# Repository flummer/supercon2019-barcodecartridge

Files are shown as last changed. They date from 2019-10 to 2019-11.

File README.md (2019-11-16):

# Barcode reader Cartridge for the 2019 Hackaday Superconference Badge

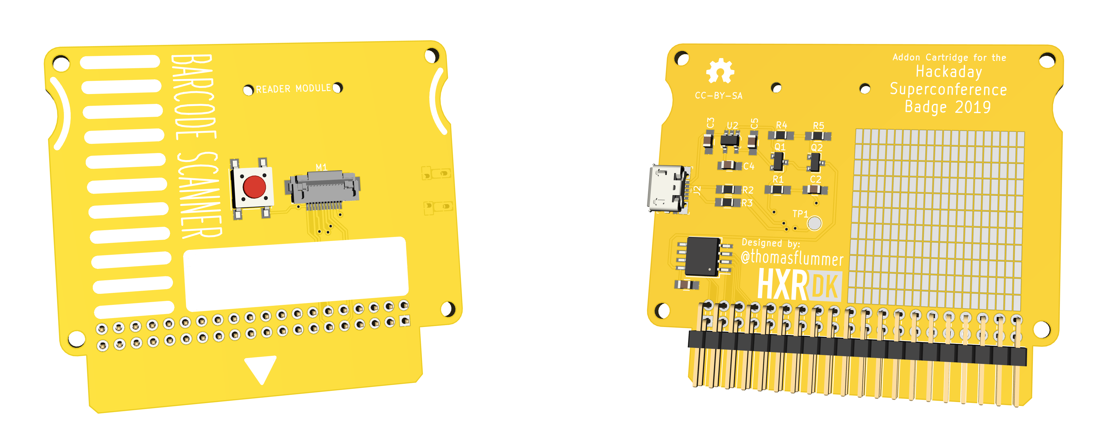
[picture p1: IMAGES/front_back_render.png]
Barcode Cartridge render


This is designed to use the GM65 barcode reader module, that supports both 1D and 2D barcodes and is able to read from a screen (eg. a smartphone or the screen on the badge)

This cartridge is based on the [unofficial Superconference 2019 Badge Cartridge template](https://github.com/flummer/supercon2019-cartridgetemplate) and hence include the w25q128 SPI flash and a 100nF cap in addition to the 2x20 pin angled male pin header for the badge connection. The flash allows badge configurations and firmware specific to this cartridge to be loaded from the cartridge it self making it selfcontained.

## Version 1.2 update

This updated version fixes an error in the pin connections on the cartridge connector (the two columns was flipped for some signals).

## Special note about the original version

If you want to use a PCB based on the original version with incorrect connections, it is possible to make a hardware hack on the 20x2 angeled header, where you move the pins around and bend some of them a bit, very precisely.

## License

The contents of this repository is released under the following licence:

 * the "Creative Commons Attribution-ShareAlike 4.0 International License"
   (CC BY-SA 4.0) full text of this license is included in the LICENSE file
   and a copy can also be found at
   http://creativecommons.org/licenses/by-sa/4.0/

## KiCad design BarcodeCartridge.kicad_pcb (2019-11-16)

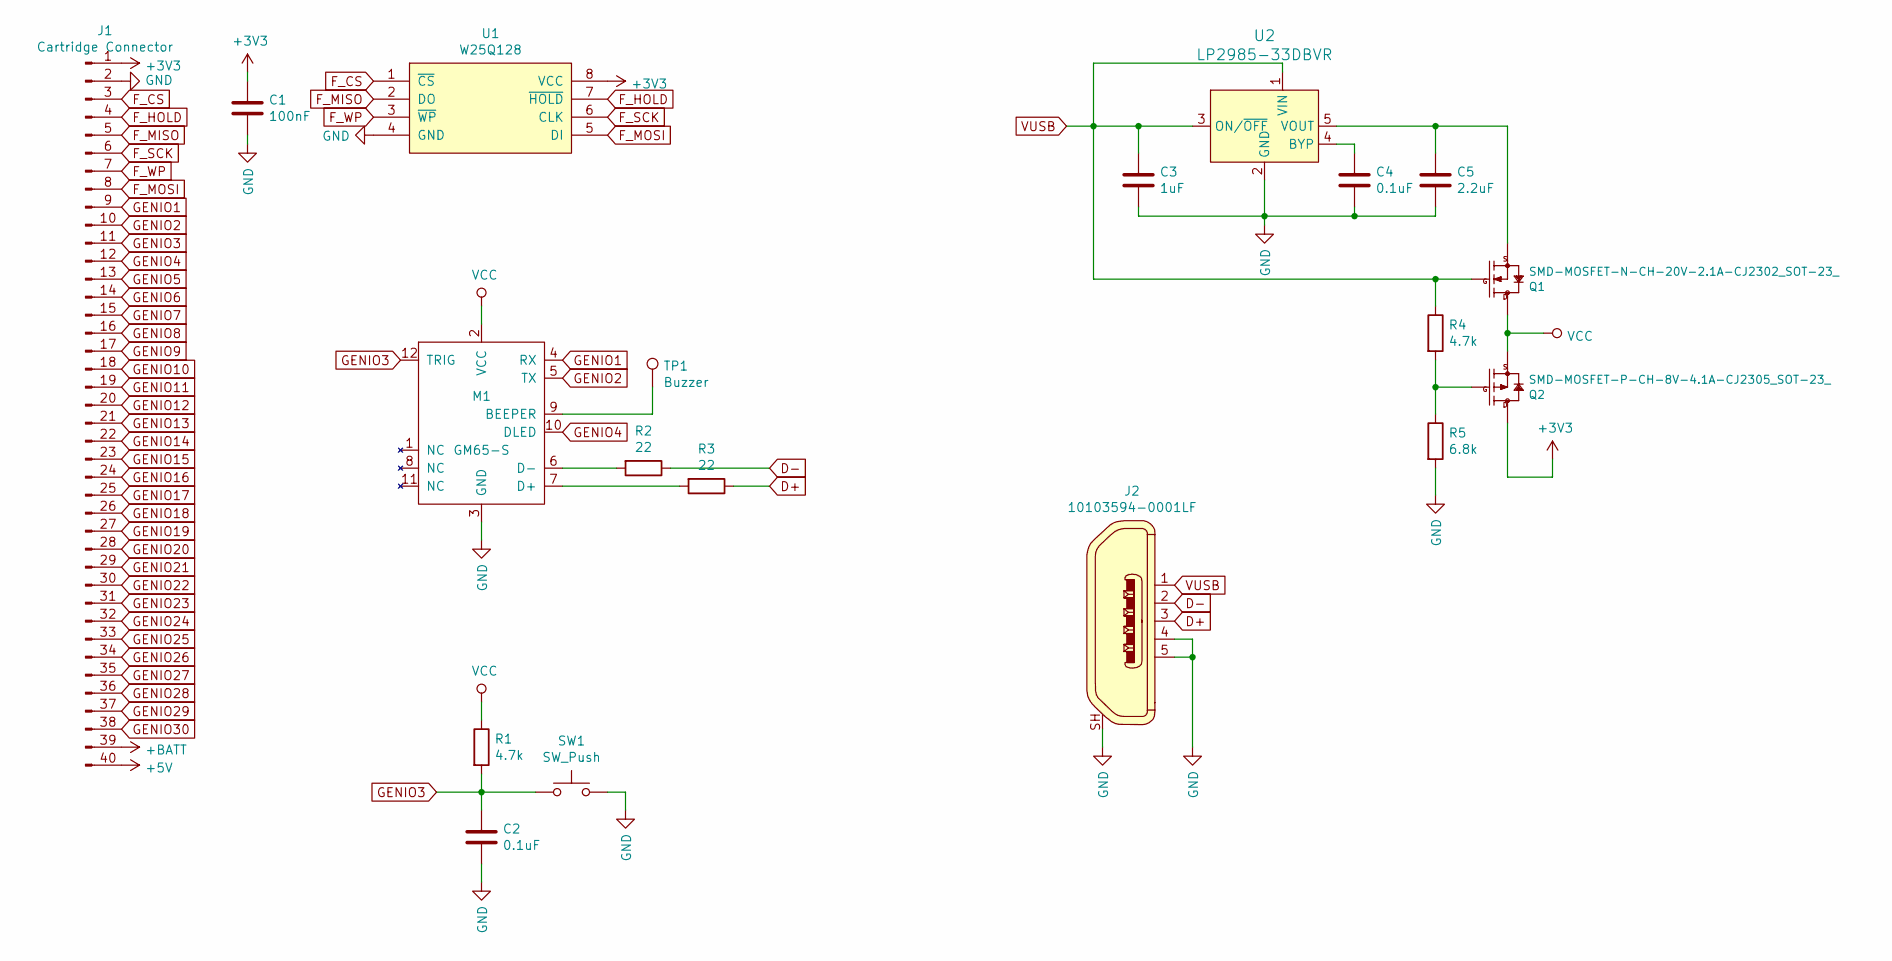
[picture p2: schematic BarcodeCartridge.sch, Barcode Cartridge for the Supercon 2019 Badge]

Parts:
C1: 100nF; C_0805_HandSoldering
C2, C4: 0.1uF; C_0805_HandSoldering
C3: 1uF; C_0805_HandSoldering
C5: 2.2uF; C_0805_HandSoldering
J1: Cartridge Connector; Supercon_Cartridge_40pin_Connector
J2: 10103594-0001LF; USB_Micro_B_Female_10103594-0001LF; MPN 10103594-0001LF; Digi-Key_PN 609-4050-1-ND
M1: GM65-S; SD-52892-044
Q1: SMD-MOSFET-N-CH-20V-2.1A-CJ2302_SOT-23_; SOT-23; MPN CJ2302
Q2: SMD-MOSFET-P-CH-8V-4.1A-CJ2305_SOT-23_; SOT-23; MPN CJ2305
R1, R4: 4.7k; R_0805_HandSoldering
R2, R3: 22; R_0805_HandSoldering
R5: 6.8k; R_0805_HandSoldering
SW1: SW_Push; SW_SPST_PTS645
TP1: Buzzer; Test_Point_Pad_d2.0mm
U1: W25Q128; SO-8_5.3x6.2mm_Pitch1.27mm
U2: LP2985-33DBVR; SOT-753; MPN LP2985-33DBVR; Digi-Key_PN 296-18476-1-ND

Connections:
+3V3: C1.1, J1.1, Q2.3 (D), U1.8 (VCC)
+5V: J1.40
+BATT: J1.39
D+: J2.3, R3.1
D-: J2.2, R2.1
F_CS: J1.3, U1.1 (~CS)
F_HOLD: J1.4, U1.7 (~HOLD)
F_MISO: J1.5, U1.2 (DO)
F_MOSI: J1.8, U1.5 (DI)
F_SCK: J1.6, U1.6 (CLK)
F_WP: J1.7, U1.3 (~WP)
GENIO1: J1.9, M1.4 (RX)
GENIO2: J1.10, M1.5 (TX)
GENIO3: C2.1, J1.11, M1.12 (TRIG), R1.2, SW1.1
GENIO4: J1.12, M1.10 (DLED)
GENIO5: J1.13
GENIO6: J1.14
GENIO7: J1.15
GENIO8: J1.16
GENIO9: J1.17
GENIO10: J1.18
GENIO11: J1.19
GENIO12: J1.20
GENIO13: J1.21
GENIO14: J1.22
GENIO15: J1.23
GENIO16: J1.24
GENIO17: J1.25
GENIO18: J1.26
GENIO19: J1.27
GENIO20: J1.28
GENIO21: J1.29
GENIO22: J1.30
GENIO23: J1.31
GENIO24: J1.32
GENIO25: J1.33
GENIO26: J1.34
GENIO27: J1.35
GENIO28: J1.36
GENIO29: J1.37
GENIO30: J1.38
GND: C1.2, C2.2, C3.2, C4.2, C5.2, J1.2, J2.4, J2.5, J2.SH, M1.3 (GND), R5.2, SW1.2, U1.4 (GND), U2.2 (GND)
unnamed: C4.1, U2.4 (BYP)
unnamed: C5.1, Q1.2 (S), U2.5 (VOUT)
unnamed: M1.6 (D-), R2.2
unnamed: M1.7 (D+), R3.2
unnamed: M1.9 (BEEPER), TP1.1
unnamed: Q2.1 (G), R4.2, R5.1
VCC: M1.2 (VCC), Q1.3 (D), Q2.2 (S), R1.1
VUSB: C3.1, J2.1, Q1.1 (G), R4.1, U2.1 (VIN), U2.3 (ON/~OFF)

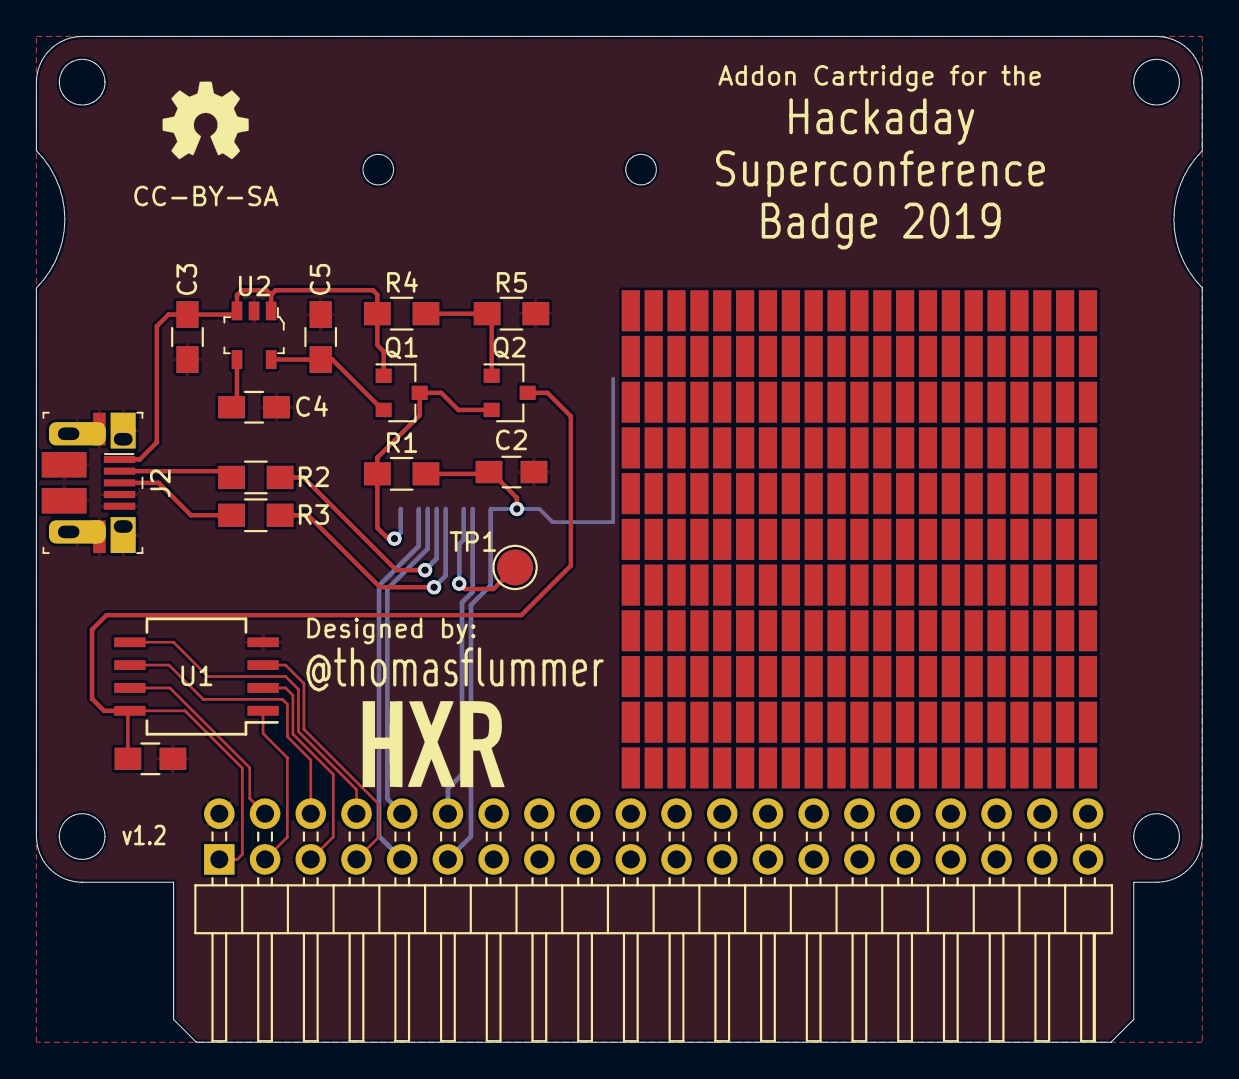
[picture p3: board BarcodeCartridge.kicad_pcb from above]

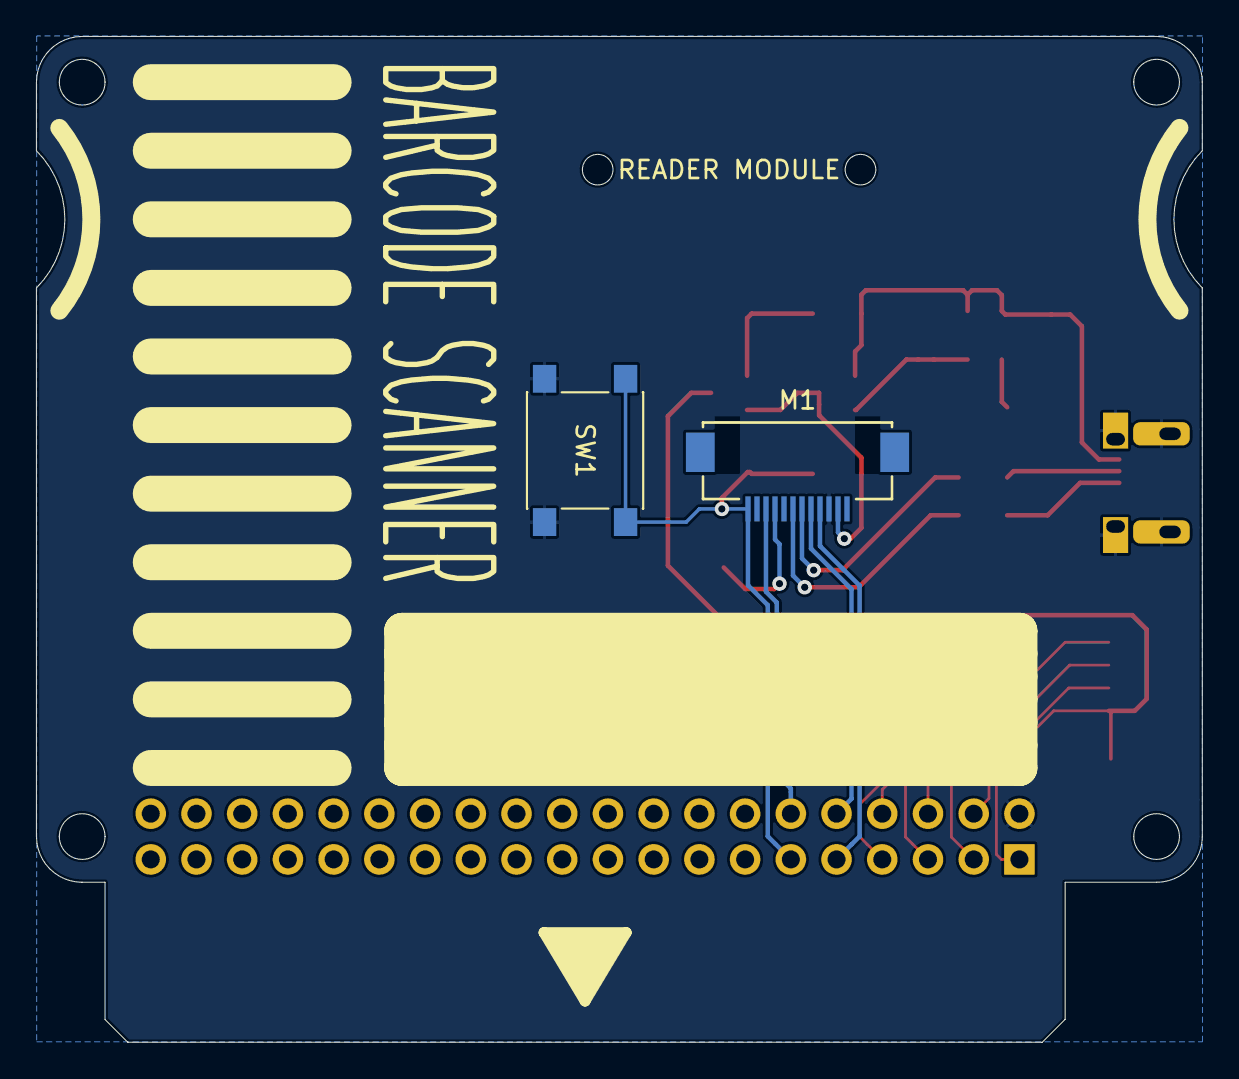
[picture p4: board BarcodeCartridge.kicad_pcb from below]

Board: 2 copper layers, 64.8 x 55.9 mm, 20 parts (3 on the bottom side), 22 nets.

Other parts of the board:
READER MODULE: GM65-S

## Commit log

2019-10-26 Renamed template files and updated README
    [BarcodeCartridge.kicad_pcb, BarcodeCartridge.sch]
2019-10-26 First design of the Barcode reader cartridge
    Also updated:
    - README
    - Render image
    - .gitignore
    [BarcodeCartridge.kicad_pcb, BarcodeCartridge.sch]
2019-10-29 Updated README and gerber export settings
    [BarcodeCartridge.kicad_pcb]
2019-11-16 Fixed error in cartridge connector pin assignments
    Updated to version 1.2
    [BarcodeCartridge.kicad_pcb, BarcodeCartridge.sch]
